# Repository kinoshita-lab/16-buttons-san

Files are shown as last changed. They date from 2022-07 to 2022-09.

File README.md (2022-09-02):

# 16-buttons-san

## PCB with 16 buttons and shift registers

"16-buttons-san" is a handy PCB with 16 buttons, and shift resistors and can also cascade next same PCB.

## Kit contents

- Pre-assembled circuit board
- 1x5 pin socket

## How to assemble

Solder the included 1x05 pin socket into the following place below:
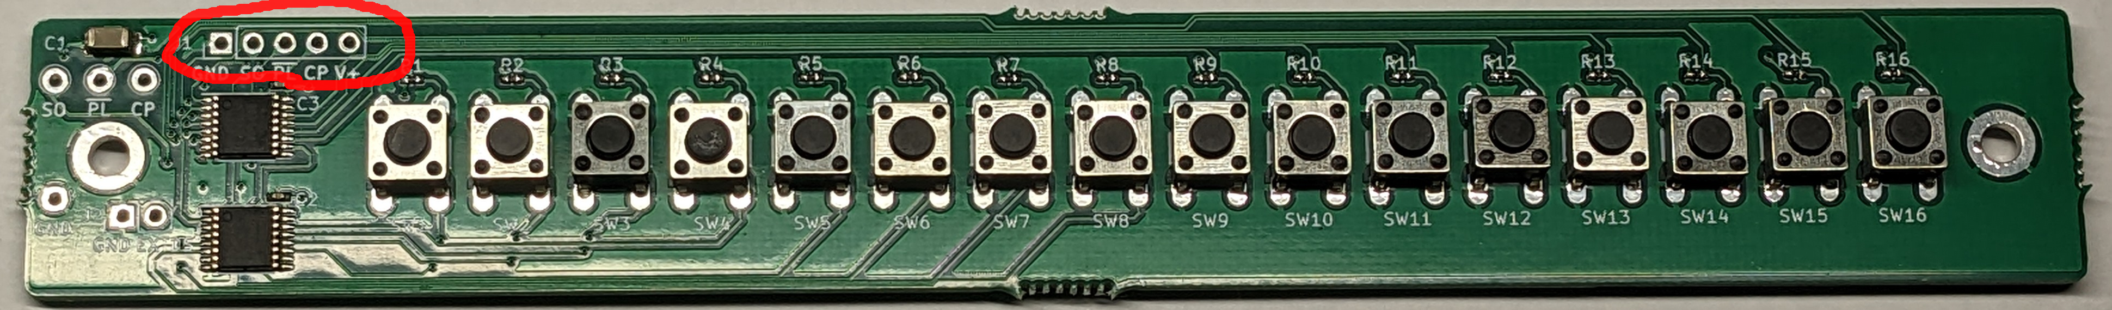
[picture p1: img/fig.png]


## Sample program

Please refer to the exapmles/Simple
<https://github.com/kinoshita-lab/16-buttons-san/tree/main/software/examples/Simple>

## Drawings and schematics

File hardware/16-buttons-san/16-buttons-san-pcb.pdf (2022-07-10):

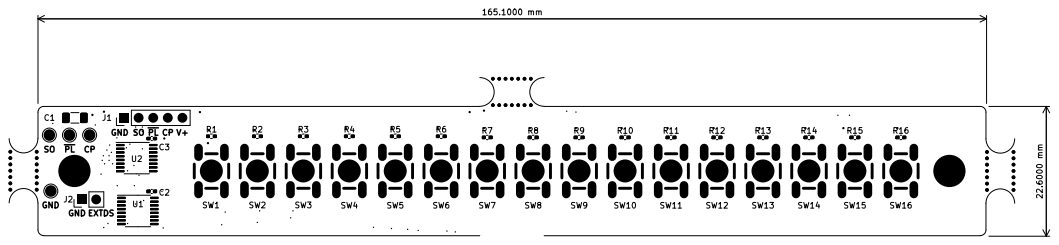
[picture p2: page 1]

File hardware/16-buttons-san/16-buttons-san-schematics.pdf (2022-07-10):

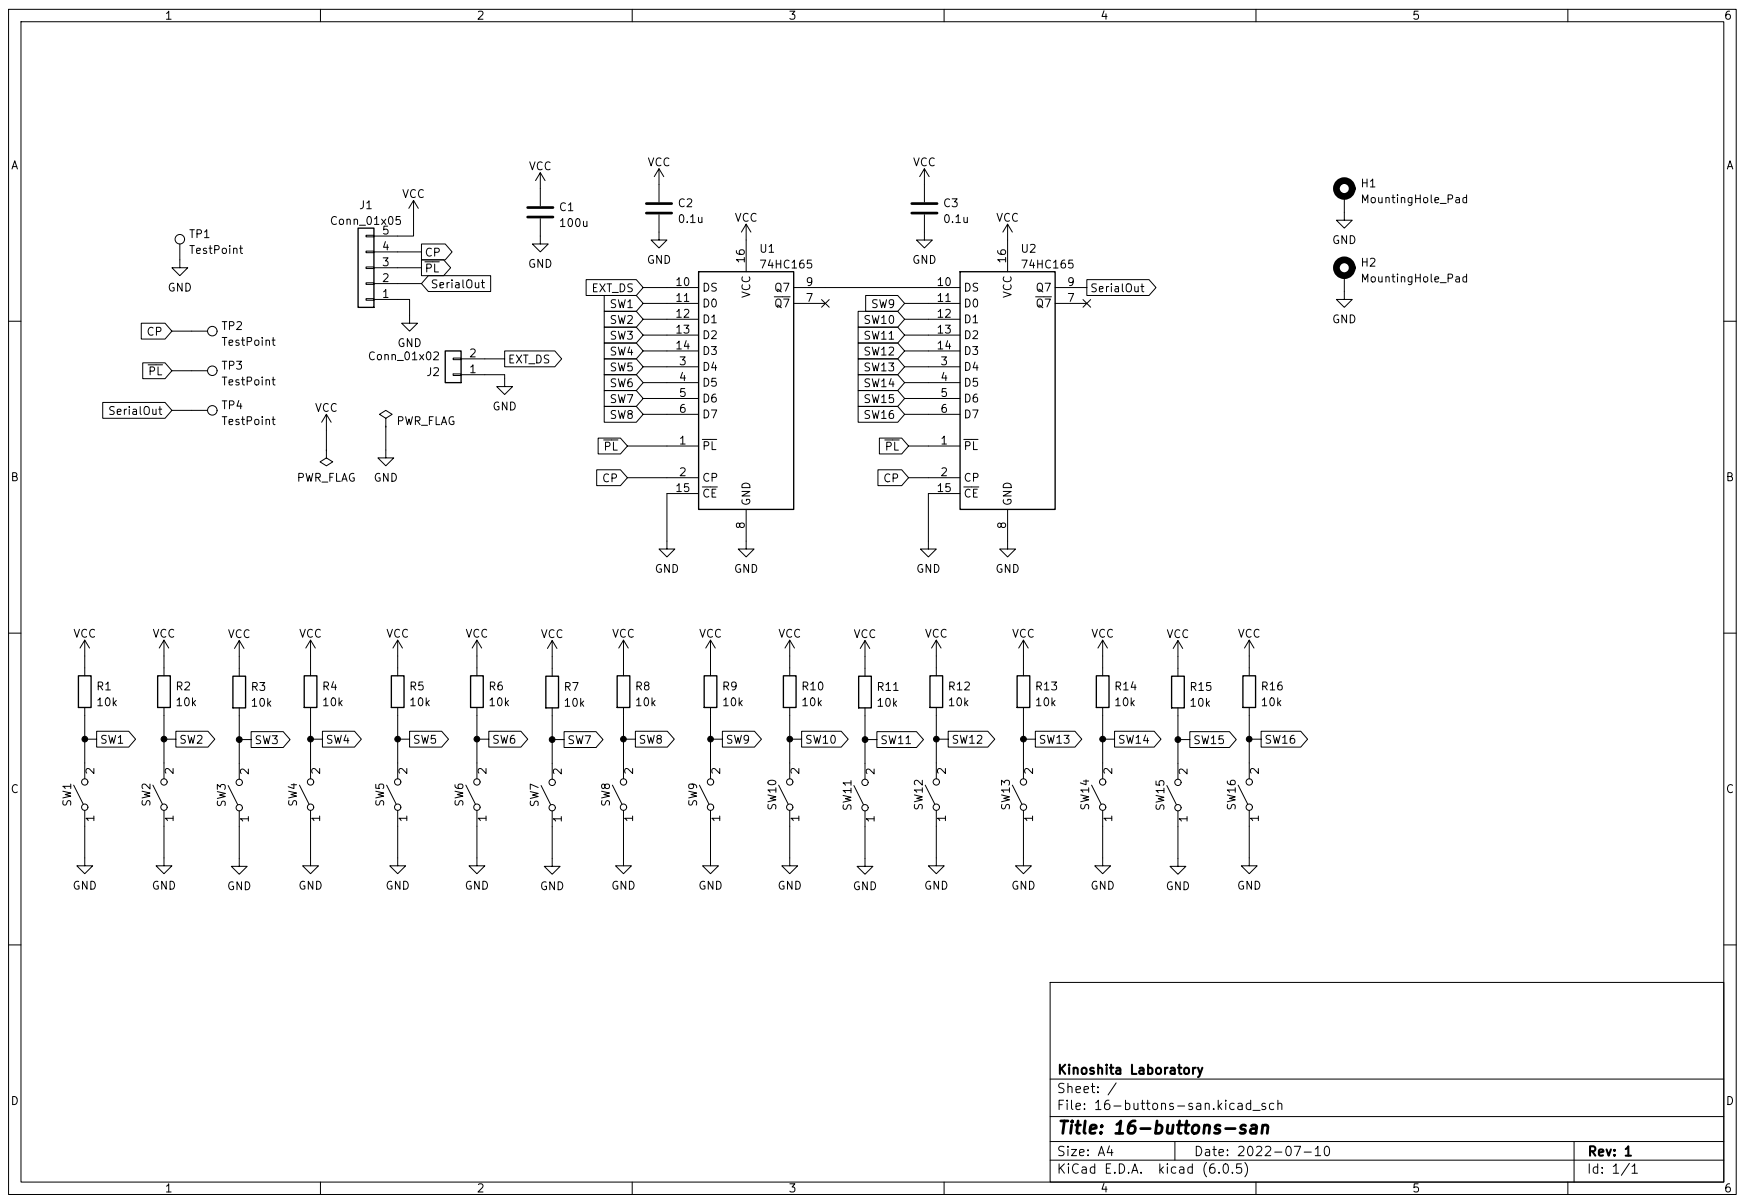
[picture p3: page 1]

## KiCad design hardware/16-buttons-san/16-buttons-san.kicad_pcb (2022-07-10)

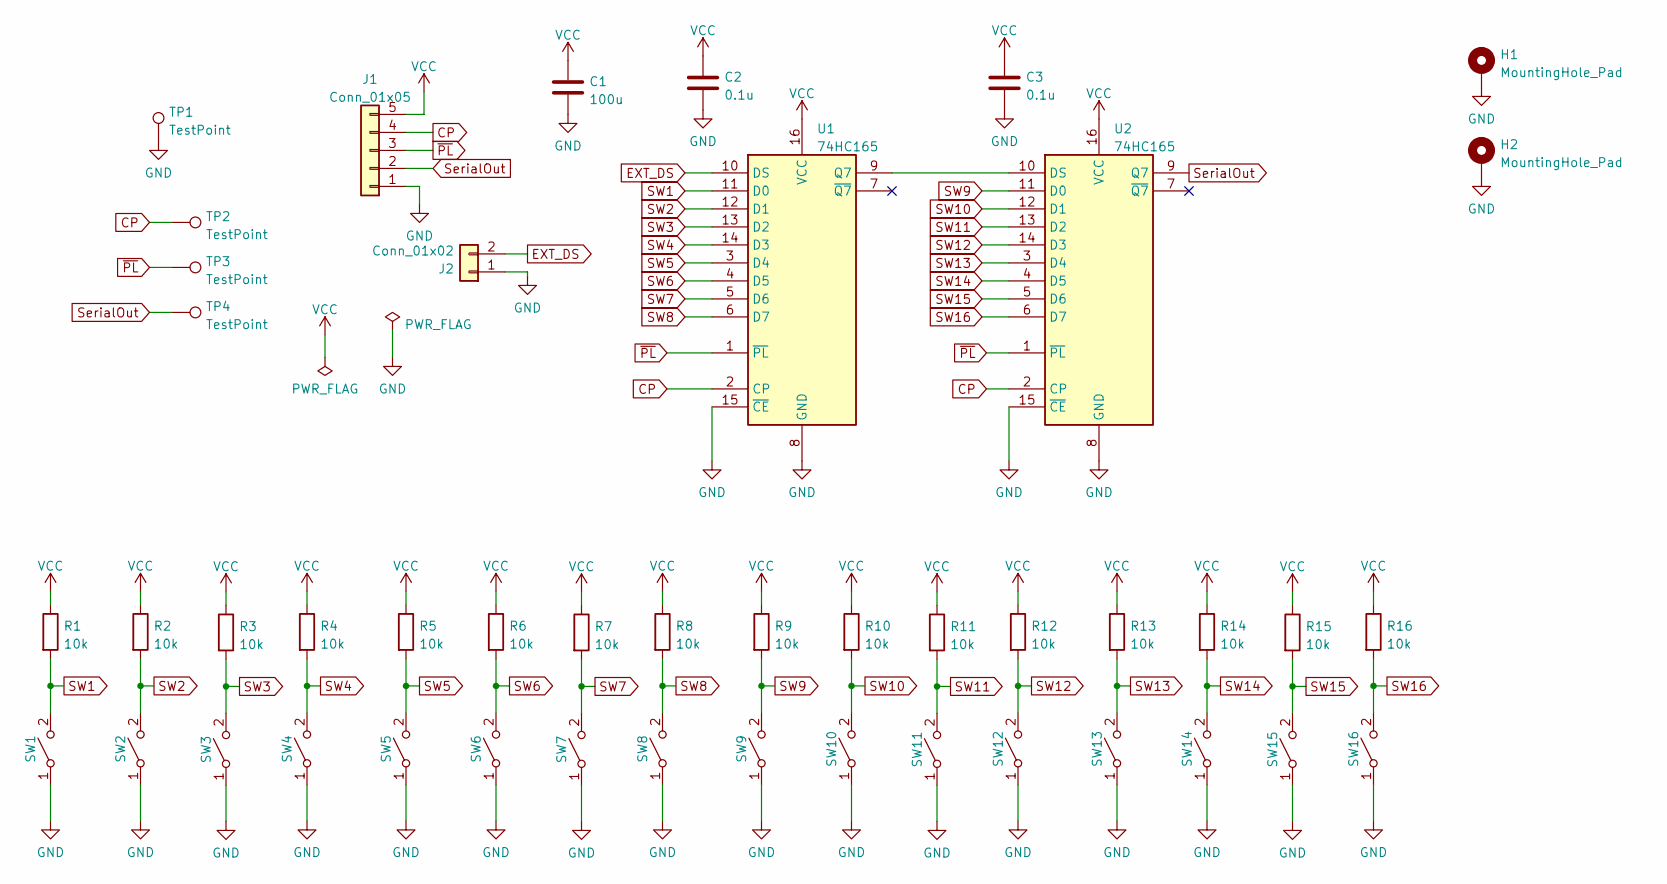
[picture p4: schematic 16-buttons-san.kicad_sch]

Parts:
C1: 100u; C_1206_3216Metric_Pad1.33x1.80mm_HandSolder; LCSC C312983
C2, C3: 0.1u; C_0402_1005Metric_Pad0.74x0.62mm_HandSolder; LCSC C1525
H1, H2: MountingHole_Pad; MountingHole_3.2mm_M3_DIN965_Pad
J1: Conn_01x05; PinHeader_1x05_P2.54mm_Vertical
J2: Conn_01x02; PinHeader_1x02_P2.54mm_Vertical
R1, R2, R3, R4, R5, R6, R7, R8, R9, R10, R11, R12, R13, R14, R15, R16: 10k; R_0402_1005Metric_Pad0.72x0.64mm_HandSolder; LCSC C25744
SW1, SW2, SW3, SW4, SW5, SW6, SW7, SW8, SW9, SW10, SW11, SW12, SW13, SW14, SW15, SW16: SW_SPST; SW_Tactile_6mm_x_6mm_Futsuuno_Akizuki_nadoniaruyatsu; LCSC C2828575
TP1, TP2, TP3, TP4: TestPoint; TestPoint_THTPad_D2.0mm_Drill1.0mm
U1, U2: 74HC165; TSSOP-16_4.4x5mm_P0.65mm; LCSC C80696

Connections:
CP: J1.4, TP2.1, U1.2 (CP), U2.2 (CP)
EXT_DS: J2.2, U1.10 (DS)
GND: C1.2, C2.2, C3.2, H1.1, H2.1, J1.1, J2.1, SW1.1 (A), SW2.1 (A), SW3.1 (A), SW4.1 (A), SW5.1 (A), SW6.1 (A), SW7.1 (A), SW8.1 (A), SW9.1 (A), SW10.1 (A), SW11.1 (A), SW12.1 (A), SW13.1 (A), SW14.1 (A), SW15.1 (A), SW16.1 (A), TP1.1, U1.8 (GND), U1.15 (~CE), U2.8 (GND), U2.15 (~CE)
unnamed: U1.9 (Q7), U2.10 (DS)
SW1: R1.2, SW1.2 (B), U1.11 (D0)
SW2: R2.2, SW2.2 (B), U1.12 (D1)
SW3: R3.2, SW3.2 (B), U1.13 (D2)
SW4: R4.2, SW4.2 (B), U1.14 (D3)
SW5: R5.2, SW5.2 (B), U1.3 (D4)
SW6: R6.2, SW6.2 (B), U1.4 (D5)
SW7: R7.2, SW7.2 (B), U1.5 (D6)
SW8: R8.2, SW8.2 (B), U1.6 (D7)
SW9: R9.2, SW9.2 (B), U2.11 (D0)
SW10: R10.2, SW10.2 (B), U2.12 (D1)
SW11: R11.2, SW11.2 (B), U2.13 (D2)
SW12: R12.2, SW12.2 (B), U2.14 (D3)
SW13: R13.2, SW13.2 (B), U2.3 (D4)
SW14: R14.2, SW14.2 (B), U2.4 (D5)
SW15: R15.2, SW15.2 (B), U2.5 (D6)
SW16: R16.2, SW16.2 (B), U2.6 (D7)
SerialOut: J1.2, TP4.1, U2.9 (Q7)
VCC: C1.1, C2.1, C3.1, J1.5, R1.1, R2.1, R3.1, R4.1, R5.1, R6.1, R7.1, R8.1, R9.1, R10.1, R11.1, R12.1, R13.1, R14.1, R15.1, R16.1, U1.16 (VCC), U2.16 (VCC)
~PL: J1.3, TP3.1, U1.1 (~PL), U2.1 (~PL)

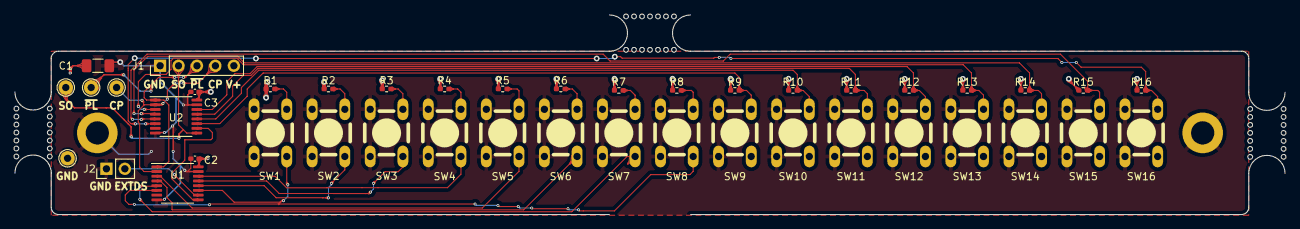
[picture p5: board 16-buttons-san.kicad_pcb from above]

Board: 2 copper layers, 175.0 x 27.5 mm, 45 parts (0 on the bottom side), 23 nets.

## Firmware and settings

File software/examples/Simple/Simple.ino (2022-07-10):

#include <Arduino.h>
#include "ShiftregisterSwScanner.h"

constexpr size_t NUM_SW = 16;
constexpr uint32_t PIN_SERIAL_OUT = 4;
constexpr uint32_t PIN_NPL = 5;
constexpr uint32_t PIN_CP = 6;

int buffer[NUM_SW] = {};
void onSwitchChanged(const uint32_t switch_index, const int off_on) {
  buffer[switch_index] = off_on;

  for (auto i = 0u; i < NUM_SW; ++i) {
    Serial.print(buffer[i] ? 1 : 0);
  }
  Serial.println("");
}

kinoshita_lab::ShiftregisterSwScanner swScanner(PIN_NPL, PIN_CP, PIN_SERIAL_OUT,
                                                onSwitchChanged, NUM_SW);

void setup() {
  Serial.begin(115200);
  // put your setup code here, to run once:
}

void loop() {
  swScanner.update();
  // delay(100);
  //  put your main code here, to run repeatedly:
}

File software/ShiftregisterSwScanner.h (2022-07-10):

/**
 * @file ShiftregisterSwScanner.h
 * @brief
 *
 * @author Kazuki Saita <saita@kinoshita-lab.com>
 *
 * Copyright (c) 2022 Kinoshita Lab. All rights reserved.
 *
 */

#pragma once
#ifndef SHIFTREGISTERSWSCANNER_H
#define SHIFTREGISTERSWSCANNER_H

#include <stdint.h>
#include <stddef.h>
#include <assert.h>
#include <Arduino.h>

namespace kinoshita_lab {

  class ShiftregisterSwScanner {
   public:
    typedef void (*SwitchHandler)(uint32_t switch_index, const int off_on);
    enum {
      DEFAULT_NUM_SWITCH = 16,
      DEFAULT_SCAN_PERIOD_MSEC = 4,
    };

    enum InternalState {
      Init,
      LoadStart,
      ReadEachBits,
      WaitNext,
      UnknownState = 0xff,
    };

    ShiftregisterSwScanner(
        const uint8_t npl_pin, const uint8_t clock_pin,
        const uint8_t output_pin, SwitchHandler handler = nullptr,
        const size_t num_switches = DEFAULT_NUM_SWITCH,
        const unsigned int scan_period = DEFAULT_SCAN_PERIOD_MSEC)
        : pins_(npl_pin, clock_pin, output_pin),
          handler_(handler),
          num_switches_(num_switches) {
      scan_buffers_ = new uint8_t[num_switches_];
      former_scan_buffers_ = new uint8_t[num_switches_];
      switch_status_ = new uint8_t[num_switches_];

      // initialize switch status
      for (auto i = 0u; i < num_switches_; ++i) {
        scan_buffers_[i] = 1;
        former_scan_buffers_[i] = 1;
        switch_status_[i] = 1;
      }
      pinMode(npl_pin, OUTPUT);
      pinMode(clock_pin, OUTPUT);
      pinMode(output_pin, INPUT_PULLUP);

      setState(Init);
    }

    virtual ~ShiftregisterSwScanner() {
      delete[] scan_buffers_;
      delete[] former_scan_buffers_;
      delete[] switch_status_;
    }

    void update() {
      switch (status_) {
        case Init:
          setState(LoadStart);
          break;
        case LoadStart:
          setState(ReadEachBits);
          break;
        case ReadEachBits: {
          for (auto i = 0u; i < num_switches_; ++i) {
            digitalWrite(pins_.clock_pin, LOW);
            const auto read_data = digitalRead(pins_.output_pin);
            scan_buffers_[num_switches_ - i - 1] = read_data;
            digitalWrite(pins_.clock_pin, HIGH);
          }
          updateSwitchStatus();
          setState(WaitNext);
          break;
          case WaitNext: {
            const auto current = millis();
            const auto delta = current - wait_start_;
            if (delta > scan_period_) {
              setState(LoadStart);
            }
          } break;
          default:
            break;
        }
      }
    };

   protected:
    uint8_t status_ = UnknownState;
    size_t will_read_switch_ = 0;

    void setState(const int status) {
      status_ = status;
      assert(pins_.npl_pin != Pins::INVALID_PIN_CONFIGURATION);
      assert(pins_.clock_pin != Pins::INVALID_PIN_CONFIGURATION);
      assert(pins_.output_pin != Pins::INVALID_PIN_CONFIGURATION);

      switch (status_) {
        case Init:
          digitalWrite(pins_.npl_pin, HIGH);
          digitalWrite(pins_.clock_pin, LOW);
          break;
        case LoadStart:
          digitalWrite(pins_.npl_pin, LOW);
          digitalWrite(pins_.clock_pin, LOW);
          will_read_switch_ = 0;
          break;
        case ReadEachBits:
          digitalWrite(pins_.clock_pin, LOW);
          digitalWrite(pins_.npl_pin, HIGH);
          break;
        case WaitNext:
          wait_start_ = millis();
          digitalWrite(pins_.npl_pin, HIGH);
          digitalWrite(pins_.clock_pin, LOW);
          break;
        default:
          break;
      }
    }

    void updateSwitchStatus() {
      for (auto i = 0u; i < num_switches_; ++i) {
        if (scan_buffers_[i] == former_scan_buffers_[i]) {
          const auto new_status = scan_buffers_[i];
          auto current_status = switch_status_[i];
          if (current_status != new_status) {
            switch_status_[i] = (new_status);
            const auto notification_status =
                !switch_status_[i];  // NOTE: inverted!! off = HIGH, on = LOW
            if (handler_) {
              (*handler_)(i, notification_status);
            }
          }
        }
        former_scan_buffers_[i] = scan_buffers_[i];
      }
    }
    struct Pins {
      enum {
        INVALID_PIN_CONFIGURATION = 0xff,
      };
      Pins(const uint8_t npl_pin, const uint8_t clock_pin,
           const uint8_t input_pin)
          : npl_pin(npl_pin), clock_pin(clock_pin), output_pin(input_pin) {}

      Pins() = default;

      uint8_t npl_pin = INVALID_PIN_CONFIGURATION;
      uint8_t clock_pin = INVALID_PIN_CONFIGURATION;
      uint8_t output_pin = INVALID_PIN_CONFIGURATION;
    };
    Pins pins_;
    SwitchHandler handler_ = nullptr;
    uint32_t num_switches_ = DEFAULT_NUM_SWITCH;

    uint8_t * scan_buffers_ = nullptr;
    uint8_t * former_scan_buffers_ = nullptr;
    uint8_t * switch_status_ = nullptr;
    uint32_t wait_start_ = 0;
    uint32_t scan_period_ = 0;

   private:
    ShiftregisterSwScanner(const ShiftregisterSwScanner &) {}
  };

}  // namespace kinoshita_lab
#endif  // SHIFTREGISTERSWSCANNER_H

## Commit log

2022-07-10 add hardware files
    [16-buttons-san.kicad_pcb, 16-buttons-san.kicad_sch]
2022-07-10 add pdf version of schematics and pcbs
    [16-buttons-san.kicad_pcb]
2022-09-02 add docs and samples
